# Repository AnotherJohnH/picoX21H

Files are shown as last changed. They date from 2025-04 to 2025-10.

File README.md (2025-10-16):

# picoX21H

picox21h

A hybrid software/hardware simulation of the Yamaha DX21, using a Raspberry Pi Pico, a YM2151 (OPM) sound chip and an I2S DAC.

[Block Diagram](docs/block_diagram.pdf)

## Status

It's a working musical instrument! Any of the 128 preset patches from the DX21 ROM (v1.5)
can be selected and played via MIDI. Patches starting to sound like the real DX21.

Working...
   + USB MIDI interface (in "peripheral" mode)
   + Physical MIDI interface
   + Basic integration of MIDI ins with the software synth framework
   + YM2151 (OPM) driver
   + PIO-based YM3012 (DAC) interface
   + Captured YM3012 format samples translated to I2S (currently driving a Pimoroni Pico Audio module)
   + 16x2 LCD display
   + Working (but currently noisy) chorus on the Pico's 2nd core (set MIDI CC12 >= 64)

To do...
   + Verify that the YM2151 can accurately replicate the sound of the YM2164, the similar but different chip used in the DX21
   + Complete the implementation of YM2151 register control from all patch parameters
   + Tune and de-noise chorus
   + Try adding a basic reverb on the audio path

## Hardware

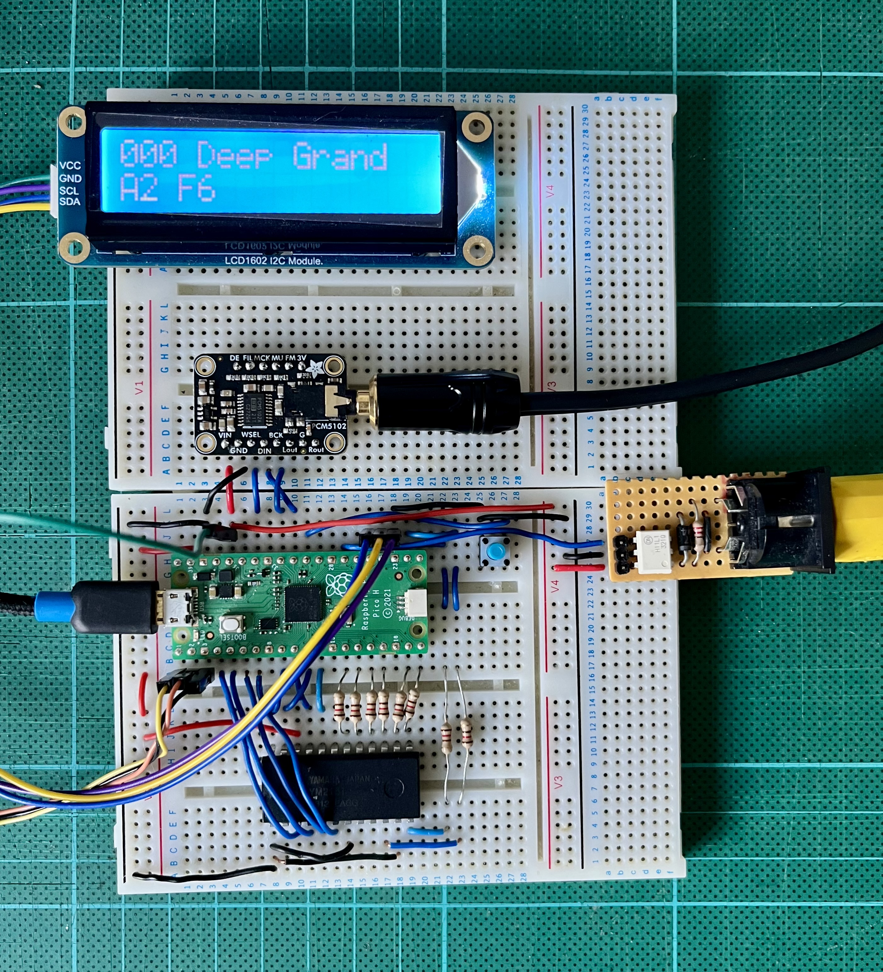
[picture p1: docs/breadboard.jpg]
prototype


[Schematic](docs/schematic.pdf) for the above.

## Software

### Checkout

This repo uses git sub-modules, so checkout using --recurse to clone all the
dependent source...

    git clone --recurse-submodules https://github.com/AnotherJohnH/picoX21H.git

ore

    git clone --recurse-submodules ssh://git@github.com/AnotherJohnH/picoX21H.git

### Software dependencies

+ https://github.com/AnotherJohnH/Platform
+ arm-none-eabi-gcc
+ cmake via UNIX make or auto detection of ninja if installed
+ Python3
+ SDL2 (only for native test target)

### Build

Being developed on MacOS but should build on Linux too.

Indirect build for supported targets, rpipico and rpipico2 with cmake and make (or ninja)...

    make

Build a single hardware target e.g. rpipico2 using cmake...

    mkdir build
    cd build
    cmake -DCMAKE_BUILD_TYPE=Release -DPLT_TARGET=rpipico2 -DCMAKE_TOOLCHAIN_FILE=Platform/MTL/rpipico2/toolchain.cmake ..
    make

flashable images will be found under the build sub-directory here...

    build/Source/picoX21H_I2S_DAC.uf2

## License

This project is licensed under the MIT License - see the [LICENSE](LICENSE) file for details

## Acknowledgements

 + The engineers at [Yamaha](https://www.yamaha.com/en/about/design/synapses/id_009)

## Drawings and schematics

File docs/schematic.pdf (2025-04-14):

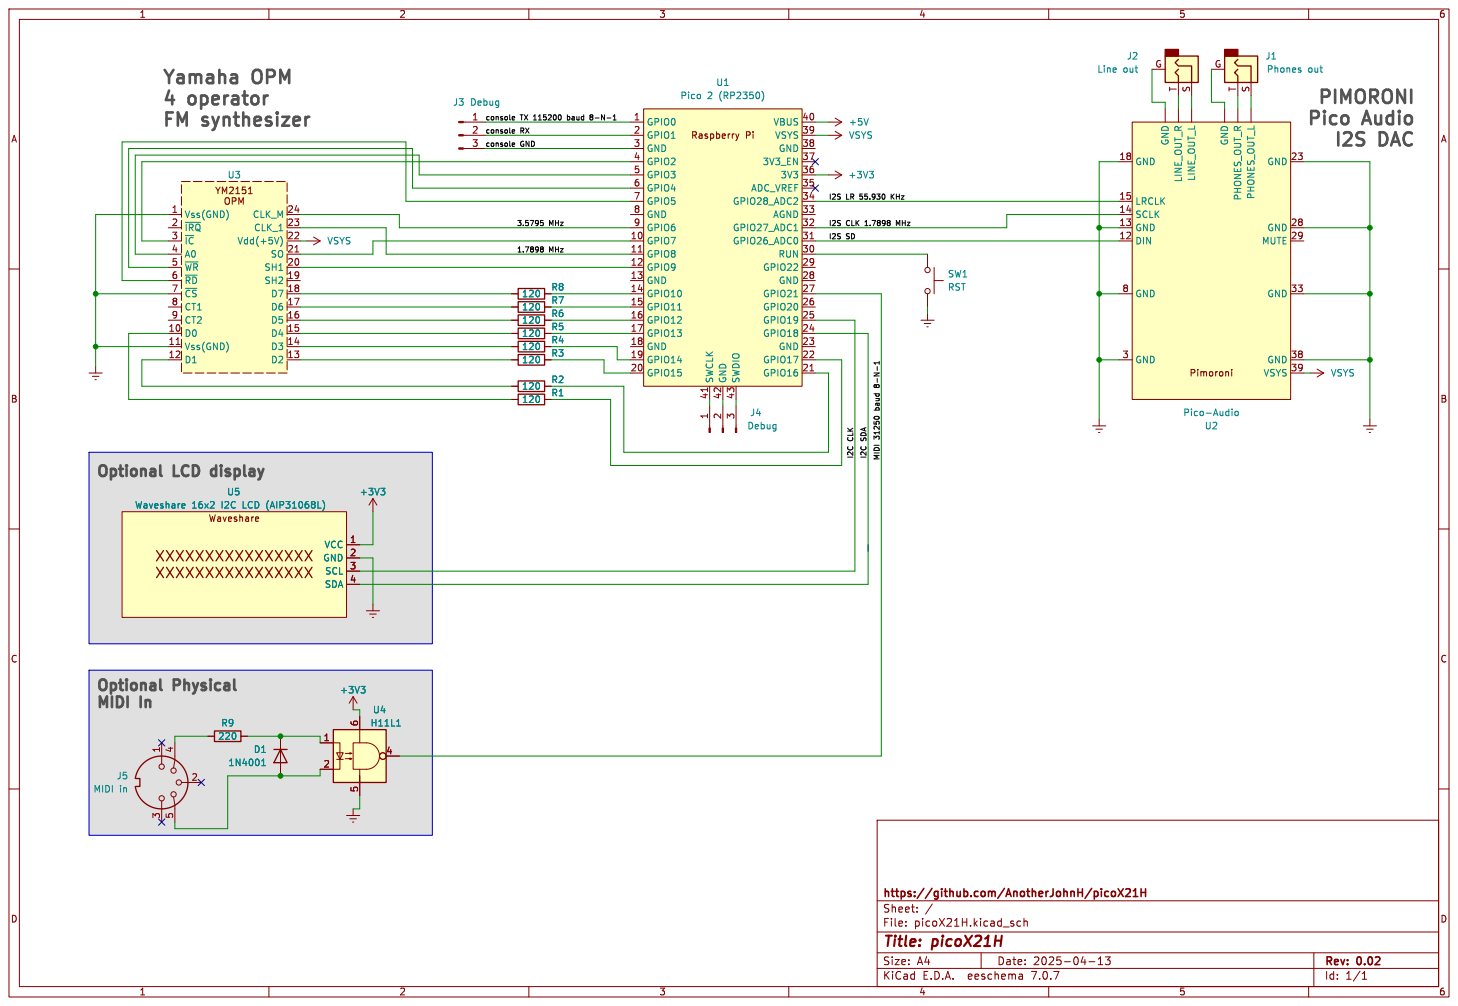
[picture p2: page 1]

File: picoX21H.kicad_sch Sheet: / https://github.com/AnotherJohnH/picoX21H

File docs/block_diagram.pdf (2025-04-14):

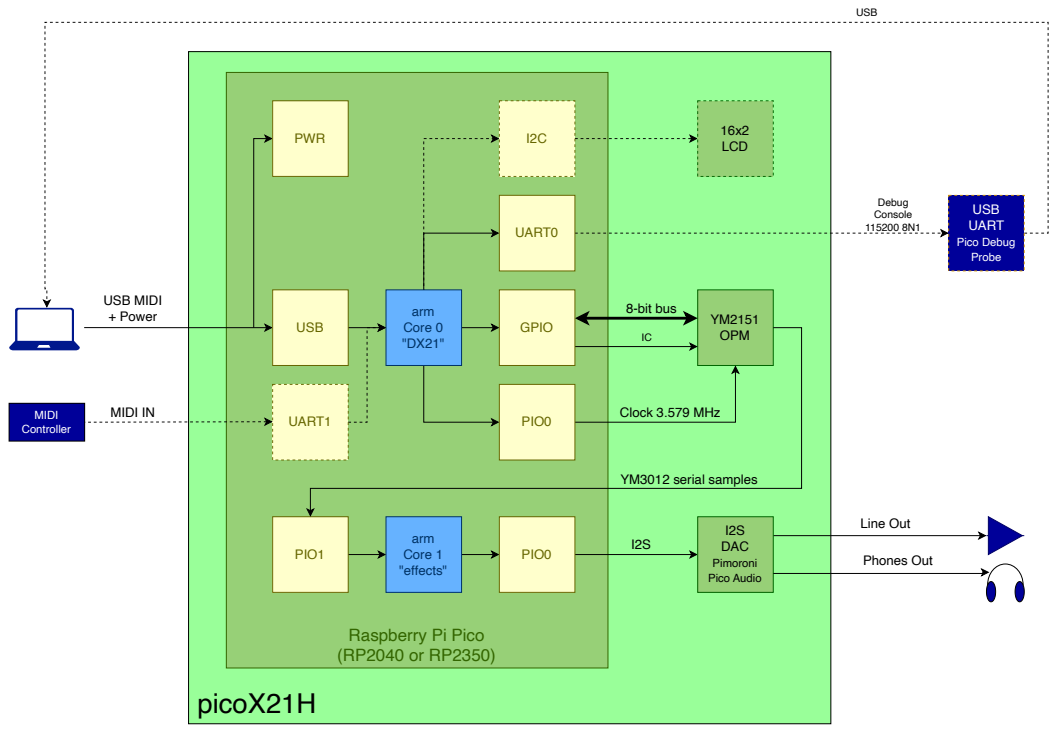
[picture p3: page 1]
picoX21H; arm Core 0 "DX21"; arm Core 1 "effects"; YM2151 OPM; USB MIDI + Power; USB; 8-bit bus; GPIO; PIO1; I2S PIO0; YM3012 serial samples; Line Out I2S; DAC; Pimoroni Pico Audio; Clock 3.579 MHz UART1; PIO0 MIDI IN; Debug Console 115200 8N1 UART0; LCD; USB UART; Pico Debug Probe; Phones Out; PWR; MIDI Controller

Raspberry Pi Pico

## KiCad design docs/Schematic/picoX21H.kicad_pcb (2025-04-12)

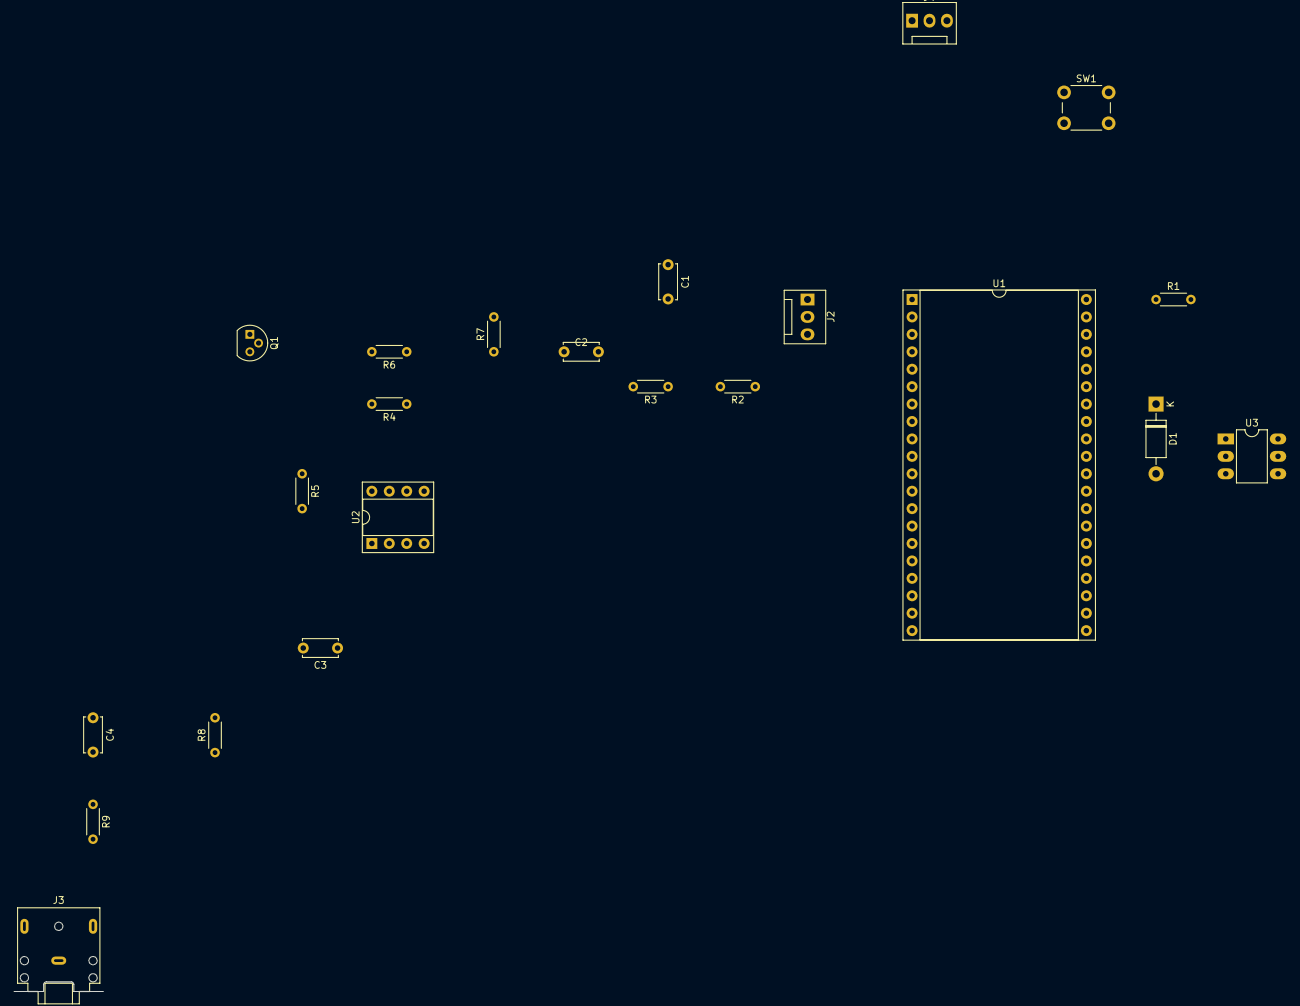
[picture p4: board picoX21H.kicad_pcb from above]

Board: 2 copper layers, 22 parts (0 on the bottom side), 22 nets, no tracks yet.

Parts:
C1, C4: 22nF; C_Disc_D5.0mm_W2.5mm_P5.00mm
C2: 220pF; C_Disc_D5.0mm_W2.5mm_P5.00mm
C3: 1nF; C_Disc_D5.0mm_W2.5mm_P5.00mm
D1: 1N4001; D_DO-41_SOD81_P10.16mm_Horizontal
J2, J4: Debug; FanPinHeader_1x03_P2.54mm_Vertical
J3: Stereo line out; Jack_3.5mm_CUI_SJ1-3523N_Horizontal
Q1: 2N2222A; TO-92
R1: 220; R_Axial_DIN0204_L3.6mm_D1.6mm_P5.08mm_Horizontal
R2, R4, R9: 33k; R_Axial_DIN0204_L3.6mm_D1.6mm_P5.08mm_Horizontal
R3: 27k; R_Axial_DIN0204_L3.6mm_D1.6mm_P5.08mm_Horizontal
R5: 220k; R_Axial_DIN0204_L3.6mm_D1.6mm_P5.08mm_Horizontal
R6: 1.8k; R_Axial_DIN0204_L3.6mm_D1.6mm_P5.08mm_Horizontal
R7: 47k; R_Axial_DIN0204_L3.6mm_D1.6mm_P5.08mm_Horizontal
R8: 2.2k; R_Axial_DIN0204_L3.6mm_D1.6mm_P5.08mm_Horizontal
SW1: RST; SW_PUSH_6mm_H5mm
U1: Pico 2 (RP2350); DIP-40_W25.4mm_Socket
U2: TL072; DIP-8_W7.62mm_Socket
U3: H11L1; DIP-6_W7.62mm_LongPads

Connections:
+3V3: U1.36 (3V3), U3.6
+5V: U1.39 (VSYS), U1.40 (VBUS)
/MIDI 31250 baud 8-N-1: U1.27 (GPIO21), U3.4
/console GND: J2.3, U1.3 (GND)
/console RX: J2.2, U1.2 (GPIO1)
/console TX 115200 baud 8-N-1: J2.1, U1.1 (GPIO0)
Earth: C1.1, R7.2, SW1.2, U2.3 (+), U2.5 (+), U3.5
unnamed: C1.2, R2.2, R3.1
unnamed: C2.2, R6.1, R7.1
unnamed: C3.2, C4.1, R8.2, U2.1
unnamed: C4.2, R9.1
unnamed: D1.2 (A), U3.2
unnamed: D1.1 (K), R1.1, U3.1
unnamed: J3.T, R9.2
unnamed: Q1.2 (B), R6.2
unnamed: Q1.3 (C), R8.1
unnamed: C3.1, Q1.1 (E), R5.2, U2.2 (-)
unnamed: R4.2, R5.1, U2.7
unnamed: C2.1, U1.4 (GPIO2)
unnamed: R2.1, U1.5 (GPIO3)
unnamed: SW1.1, U1.30 (RUN)
unnamed: R3.2, R4.1, U2.6 (-)

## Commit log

2025-03-22 Initial Synth framework
2025-04-06 Update assembler
2025-04-12 Fix typo in firmware assembler
2025-04-12 Add initial schematic
    [picoX21H.kicad_pcb, picoX21H.kicad_sch]
2025-04-12 More work on schematic
    [picoX21H.kicad_sch]
2025-04-13 Re-work pin assignments for easier layout
    + also improved documentation
    [picoX21H.kicad_sch]
2025-04-14 Further pin assignment changes
    [picoX21H.kicad_sch]
2025-04-14 Mirror schematic to give a birds eye view
    [picoX21H.kicad_sch]
2025-04-14 Display current patch info on LCD
2025-04-16 Rename PIMORONI_PICO_AUDIO config as I2S_DAC
    [picoX21H.kicad_sch]
2025-04-22 Add low pass filter to iG10090 BBD modulator
    - try and remove some noise
2025-05-16 Rename assembler files to confuse github metrics
2025-10-16 Extend pin out diagram
2025-10-18 Refactor YM2151 hardware driver
